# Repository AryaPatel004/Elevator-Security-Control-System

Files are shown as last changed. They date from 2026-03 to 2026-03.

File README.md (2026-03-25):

# Elevator Security Control System

A hardware design project for a secure elevator access system using multi-level authentication — **RFID, fingerprint, and capacitive keypad** — controlled by an **STM32G070CBT6 microcontroller**. The deliverable is a complete schematic and double-layer PCB design created in EasyEDA.

---

## 🔒 Overview

The system restricts elevator access to authenticated users only. Authentication follows a layered flow: RFID card scan → optional fingerprint or keypad verification → floor selection via touch keypad. Visual feedback is provided through a 7-segment display and 16 LEDs controlled via a shift register to minimize GPIO usage. A DC-DC converter handles the 24V to 5V step-down for the entire system.

---

## ✨ Key Features

- Multi-level authentication: RFID + fingerprint + capacitive keypad
- 16-channel touch keypad (TTP229) for floor selection
- 7-segment display for current/selected floor indication
- 74HC595 shift register to drive 16 LEDs with only 3 MCU pins
- W25Q128 serial flash for storing user credentials and access logs
- MC34063A DC-DC converter stepping 24V → 5V
- Double-layer PCB with modular section layout for clean signal routing

---

## 🔧 Components

| Component | Part Number | Purpose |
|---|---|---|
| Microcontroller | STM32G070CBT6 | Core processing and peripheral control |
| RFID Reader | RC522 | 13.56 MHz card scanning (ISO 14443A) |
| Fingerprint Sensor | ZW101 | Optical fingerprint capture and matching |
| Touch Keypad | TTP229 | 16-key capacitive input for floor selection |
| Shift Register | 74HC595 | Expand GPIO — drive 16 LEDs with 3 pins |
| Serial Flash | W25Q128 | 16MB non-volatile storage for user data |
| 7-Segment Display | — | Floor number display |
| DC-DC Converter | MC34063A | Step down 24V → regulated 5V |

### STM32G070CBT6 — Key Specs
- ARM Cortex-M0+, up to 64 MHz
- 128 KB Flash, 36 KB SRAM
- 2× I²C, 2× SPI, 4× USART
- 12-bit ADC, PWM timers
- 2.0V to 3.6V supply voltage

### RC522 RFID — Key Specs
- Operating frequency: 13.56 MHz
- Tag memory: 1 KB
- Interface: SPI
- Compatible with ISO 14443A tags (read & write)

### ZW101 Fingerprint Module — Key Specs
- Interface: UART
- Built-in optical sensor and matching processor
- Stores fingerprint templates internally

### W25Q128 Flash — Key Specs
- Capacity: 128 Mbit (16 MB)
- Interface: SPI (up to 104 MHz)
- 100,000 erase cycles per sector, >20 years data retention

---

## 🔐 Authentication Flow

```
User Approaches Elevator
        │
        ▼
  RFID Card Scan (RC522)
        │
        ├─ Not Recognized → Access Denied
        │
        └─ Recognized
                │
                ▼
   Fingerprint / Keypad Verification (ZW101 / TTP229)
                │
                ├─ Failed → Access Denied
                │
                └─ Verified
                        │
                        ▼
            Floor Selection via Touch Keypad
                        │
                        ▼
             Relay Triggered → Elevator Moves
```

---

## 🗂️ Repository Structure

```
elevator-security-control-system/
│
├── hardware/
│   ├── schematic.pdf              # Full schematic (EasyEDA export)
│   ├── pcb_design.pdf             # PCB layout (EasyEDA export)
│   └── gerber/                    # Gerber files ready for manufacturing
│       └── *.gbr
│
├── docs/
│   ├── pcb_front_back.png         # 2D front and back PCB render
│   └── bom.csv                    # Bill of Materials
│
├── .gitignore
└── README.md
```

---

## 🖥️ PCB Design Notes

Designed in **EasyEDA** as a double-layer board following this process:

1. **Schematic Creation** — All components and sub-circuits mapped out in four sections: Shift Register Circuit, Touch Button Circuit, Microcontroller Circuit, Voltage Converter Circuit, and Serial Flash Memory
2. **Footprint Assignment** — SMD packages selected to minimize board area
3. **Routing** — Short direct traces, decoupling capacitors placed close to IC power pins to reduce voltage ripple
4. **Component Grouping** — Each functional block assigned its own PCB region to simplify debugging and testing
5. **DRC & ERC Check** — Design verified for electrical and layout errors
6. **Gerber Export** — Files finalized and ready for manufacturing

---

## 🛠️ Built With

- [EasyEDA](https://easyeda.com/) — Schematic and PCB design
- [STM32G070CBT6 Datasheet](https://www.st.com/en/microcontrollers-microprocessors/stm32g070cb.html)
- [MFRC522 Datasheet](https://www.nxp.com/docs/en/data-sheet/MFRC522.pdf)
- [W25Q128 Datasheet](https://www.winbond.com/resource-files/w25q128jv%20spi%20revc%2011162016.pdf)

---

## 🔮 Future Scope

- Firmware development for STM32 to implement the full authentication logic
- Cloud connectivity for remote access control and audit logging
- Real-time elevator status reporting via wireless interface

---

## 👤 Author

**Arya Sureshbhai Patel**

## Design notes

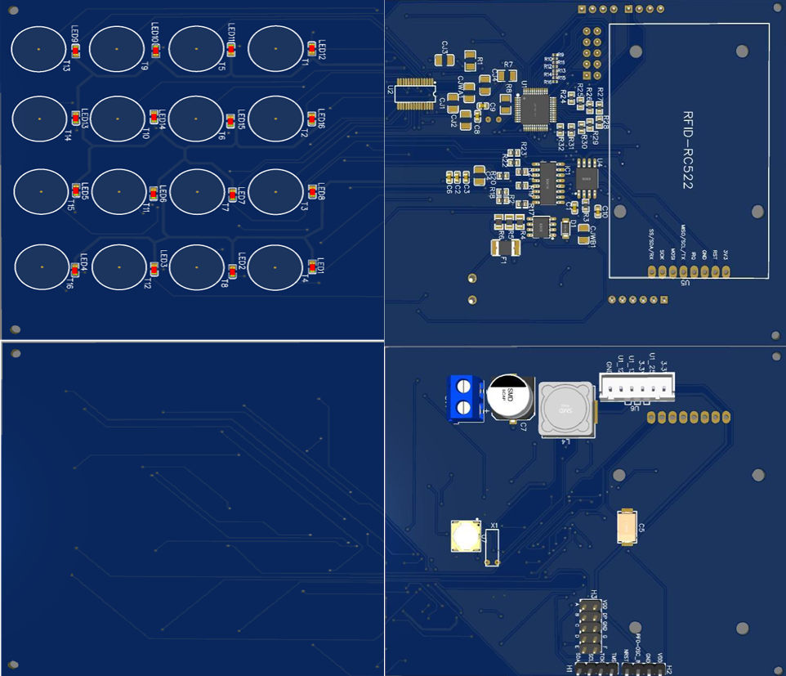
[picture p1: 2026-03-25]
docs/pcb_front_back.png

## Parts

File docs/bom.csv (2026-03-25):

ID | Name | Designator | Footprint | Quantity | Manufacturer Part | Manufacturer | Supplier | Supplier Part | Price | Pins | 3DModel | Contributor | JLCPCB Part Class | LCSC Assembly | SMT Type | Value | image | link
1 | 100uF | C7 | CAP-SMD_BD10.0-L10.3-W10.3-RD | 1 | VZH101M1HTR-1010 | LELON | LCSC | C134808 | 0.208 | 2 | CAP-SMD_L10.3-W10.3-H7.7-LS11.0 | LCSC |  | Yes | Extend |  |  | https://item.szlcsc.com/245683.html
2 | Header-Male-2.54_1x4 | H1,H2 | HDR-TH_4P-P2.54-V-M | 2 | B-2100S04P-A110 | Ckmtw(灿科盟) | LCSC | C124378 | 0.05 | 4 | HDR-TH_4P-P2.54-M-LI-1X4P | LCSC | Extended Part |  |  |  |  | https://item.szlcsc.com/502959.html
3 | Header-Male-2.54_2x5 | H3 | HDR-TH_10P-P2.54-V-M-R2-C5-S2.54 | 1 | 2*5p排针 2.54mm | null | LCSC | C28207 |  | 10 | HDR-TH_10P-P2.54-V-M-R2-C5-S2.54 | lcsc | Extended Part |  |  |  |  | https://item.szlcsc.com/502978.html
4 | 470uF | C5 | CAP-SMD_L7.3-W4.3-R-RD | 1 | CA45-D6R3K477T | Xiangyee | LCSC | C123270 | 0.866 | 2 | CASE-E_L7.3-W4.3-H4.1 | LCSC |  | Yes | Extend |  |  | https://item.szlcsc.com/91116.html
5 | 220uH | L4 | IND-SMD_L12.5-W12.5 | 1 | SWRB1205S-221MT | Sunlord | LCSC | C169391 |  | 2 | SMD-PIND_L12.5-W12.5-H8.0 | LCSC |  | Yes | Extend |  |  | https://item.szlcsc.com/421430.html
6 | WJ128V-5.0-2P | ST1 | CONN-TH_2P-P5.00 | 1 | WJ128V-5.0-2P | KANGNEX(康奈克斯电气) | LCSC | C8269 | 0.144 | 2 | CONN-TH_2P-P5.00 | LCEDA_Lib | Extended Part |  |  |  |  | https://www.szlcsc.com/?ref=editor
7 | HDR-1X6 | U6 | CONN-TH_6P-P2.50_HX25035-6A | 1 | HDR-1X6 | null | LCSC | C9900004873 |  | 6 | CONN-TH_6P-P2.50_HX25035-6A | LCSC |  |  |  |  |  | https://item.szlcsc.com/442613.html
8 | GT-TC155C-H0060-L50 | U7 | SW-SMD_4P-G-SWITCH-GT-TC155C-H0060-L50 | 1 | GT-TC155C-H0060-L50 | G-Switch(品赞) | LCSC | C5155558 | 0.15 | 4 | SW-SMD_4P-G-SWITCH-GT-TC155C-H0060-L50 | lcsc | Extended Part |  |  |  |  | https://atta.szlcsc.com/upload/public/pdf/source/20220909/B643400E9680C6559F0793AC5053044F.pdf
9 | Xtal 32.768KHz | X1 | XTAL 32.768KHZ | 1 |  |  |  |  |  | 2 |  | Maximvs |  |  |  | 32.768KHz
10 | 100nF | C1,C2,C8 | C0805 | 3 |  |  |  |  |  | 2 | C0603_L1.6-W0.8-H0.8 | LCEDA_Lib |  |  |  |  |  | https://item.szlcsc.com/362304.html
11 | 4.7uF | C3 | C0805 | 1 |  |  |  |  |  | 2 | C0603_L1.6-W0.8-H0.8 | LCEDA_Lib |  |  |  |  |  | https://item.szlcsc.com/362304.html
12 | 10pF | C9,C10 | C0805 | 2 |  |  |  |  |  | 2 | C0603_L1.6-W0.8-H0.8 | LCEDA_Lib |  |  |  |  |  | https://item.szlcsc.com/362304.html
13 | 104 | C4 | CAP_0805 | 1 | ? |  |  |  |  | 2 |  |  |  |  |  |  |  | https://item.szlcsc.com/279183.html
14 | 1u | CJ1,CJ2,CJ3,CJ4,CJWA1,CJWB1 | CAP_0805 | 6 | ? |  |  |  |  | 2 |  |  |  |  |  |  |  | https://item.szlcsc.com/279183.html
15 | 470pF | C6 | C0805 | 1 | 0603B471K500NT | FH | LCSC | C1620 | 0.003 | 2 | C0603_L1.6-W0.8-H0.8 | 立创EDA官方封装库 |  | Yes | Basic |  |  | https://item.szlcsc.com/362304.html
16 | B5819W | D1 | SOD-123_L2.8-W1.8-LS3.7-RD | 1 | B5819W | CJ | LCSC | C8598 | 0.024 | 2 | SOD-123_L2.8-W1.8-H1.4-LS3.7 | 官方封装库 |  | Yes | Basic |  | //image.lceda.cn/szlcsc/C8598.jpg | https://item.szlcsc.com/301422.html
17 | SMD1812P110TF/33 | F1 | F1812 | 1 | SMD1812P110TF/33 | RUILON | LCSC | C21000 | 0.144 | 2 | F1812_L4.5-W3.2-H1.0 | layout |  | Yes | Extend |  | //image.lceda.cn/szlcsc/C21000.jpg | https://item.szlcsc.com/343302.html
18 | SN74HC595DR | IC1 | SOIC-16_L9.9-W3.9-P1.27-LS6.0-BL | 1 | SN74HC595DR | TI | LCSC | C10092 | 0.325 | 16 | SOIC-16_L9.9-W3.9-H1.8-LS6.0-P1.27 | 官方封装库 |  | Yes | Extend |  | //image.lceda.cn/szlcsc/C10092.jpg | https://item.szlcsc.com/241229.html
19 | LED-0603_R | LED1,LED2,LED3,LED4,LED5,LED6,LED7,LED8,LED9,LED10,LED11,LED12,LED13,LED14,LED15,LED16 | LED0603_RED | 16 | 19-217/R6C-AL1M2VY/3T | EVERLIGHT(台湾亿光) | LCSC | C72044 | 0.021 | 2 | LED0603_Red | LCEDA_01
20 | 820k | R1,R7,R8 | RES_0805 | 3 | ? |  |  |  |  | 2 |  |  |  |  |  |  |  | https://item.szlcsc.com/279183.html
21 | 11K | R2 | R0805 | 1 | 0603WAF1102T5E | UniOhm | LCSC | C25950 | 0.001 | 2 | R0603_L1.6-W0.8-H0.8 | 立创EDA官方封装库 |  | Yes | Basic |  |  | https://item.szlcsc.com/137208.html
22 | 18K | R3 | R0805 | 1 | 0603WAF1802T5E | UniOhm | LCSC | C25810 | 0.001 | 2 | R0603_L1.6-W0.8-H0.8 | 立创EDA官方封装库 |  | Yes | Basic |  |  | https://item.szlcsc.com/137208.html
23 | 220 | R17,R18,R19,R20,R21,R22,R23,R24,R25,R26,R27,R28,R29,R30,R31,R32 | R0805 | 16 | 0603WAF1102T5E | UniOhm | LCSC | C25950 | 0.001 | 2 | R0603_L1.6-W0.8-H0.8 | 立创EDA官方封装库 |  | Yes | Basic |  |  | https://item.szlcsc.com/137208.html
24 | 1 | R4,R5,R6 | R0805 | 3 | 0805W8F360LT5E | Uniroyal Elec | LCSC | C35793 |  | 2 | R0805_L2.0-W1.3-H0.6 | LCSC |  | Yes | Extend |  |  | https://item.szlcsc.com/142685.html
25 | 220 | R9,R10,R11,R12,R13,R14,R15,R16 | 0805 | 8 |  |  |  |  |  | 2 |  | easyEDA
26 | Finger Print | T1,T2,T3,T4,T5,T6,T7,T8,T9,T10,T11,T12,T13,T14,T15,T16 | TOUCHPAD | 16 |  |  |  |  |  | 1 |  | Spacehuepfer
27 | STM32G070CBT6 | U1 | LQFP-48_L7.0-W7.0-P0.50-LS9.0-BL | 1 | STM32G070CBT6 | ST(意法半导体) | LCSC | C529338 | 1.449 | 48 | LQFP-48_L7.0-W7.0-H1.4-LS9.0-P0.50 | LCSC | Extended Part |  |  |  |  | https://atta.szlcsc.com/upload/public/pdf/source/20190808/C411336_D1D2DF7683029D856BA010BA7A5BF7EA.pdf
28 | TTP229-LSF | U2 | SSOP-28_150MIL | 1 | TTP229-LSF | Tontek Design Tech | LCSC | C191601 |  | 28 |  | LCSC
29 | MC34063ADR | U3 | SOIC-8_L4.9-W3.9-P1.27-LS6.0-BL | 1 | MC34063ADR | TI | LCSC |  |  | 8 | SOIC-8_L4.9-W3.9-H1.7-LS6.0-P1.27 | 87804271zpf |  | Yes | Extend
30 | W25Q128JVSSIQ | U4 | SOIC-8_L5.3-W5.3-P1.27-LS8.0-BL | 1 | W25Q128JVSSIQ | null | LCSC | C9900009643 |  | 8 | SOIC-8_L5.3-W5.3-H1.9-LS7.9-P1.27 | LCSC | Extended Part |  |  |  |  | https://item.szlcsc.com/63461.html
31 | RC522 MODULE | U5 | RC522 | 1 |  |  |  |  |  | 8 |  | Alexander Sevbo

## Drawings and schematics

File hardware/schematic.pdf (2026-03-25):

## Shift Register Circuit

## Touch button Circuit

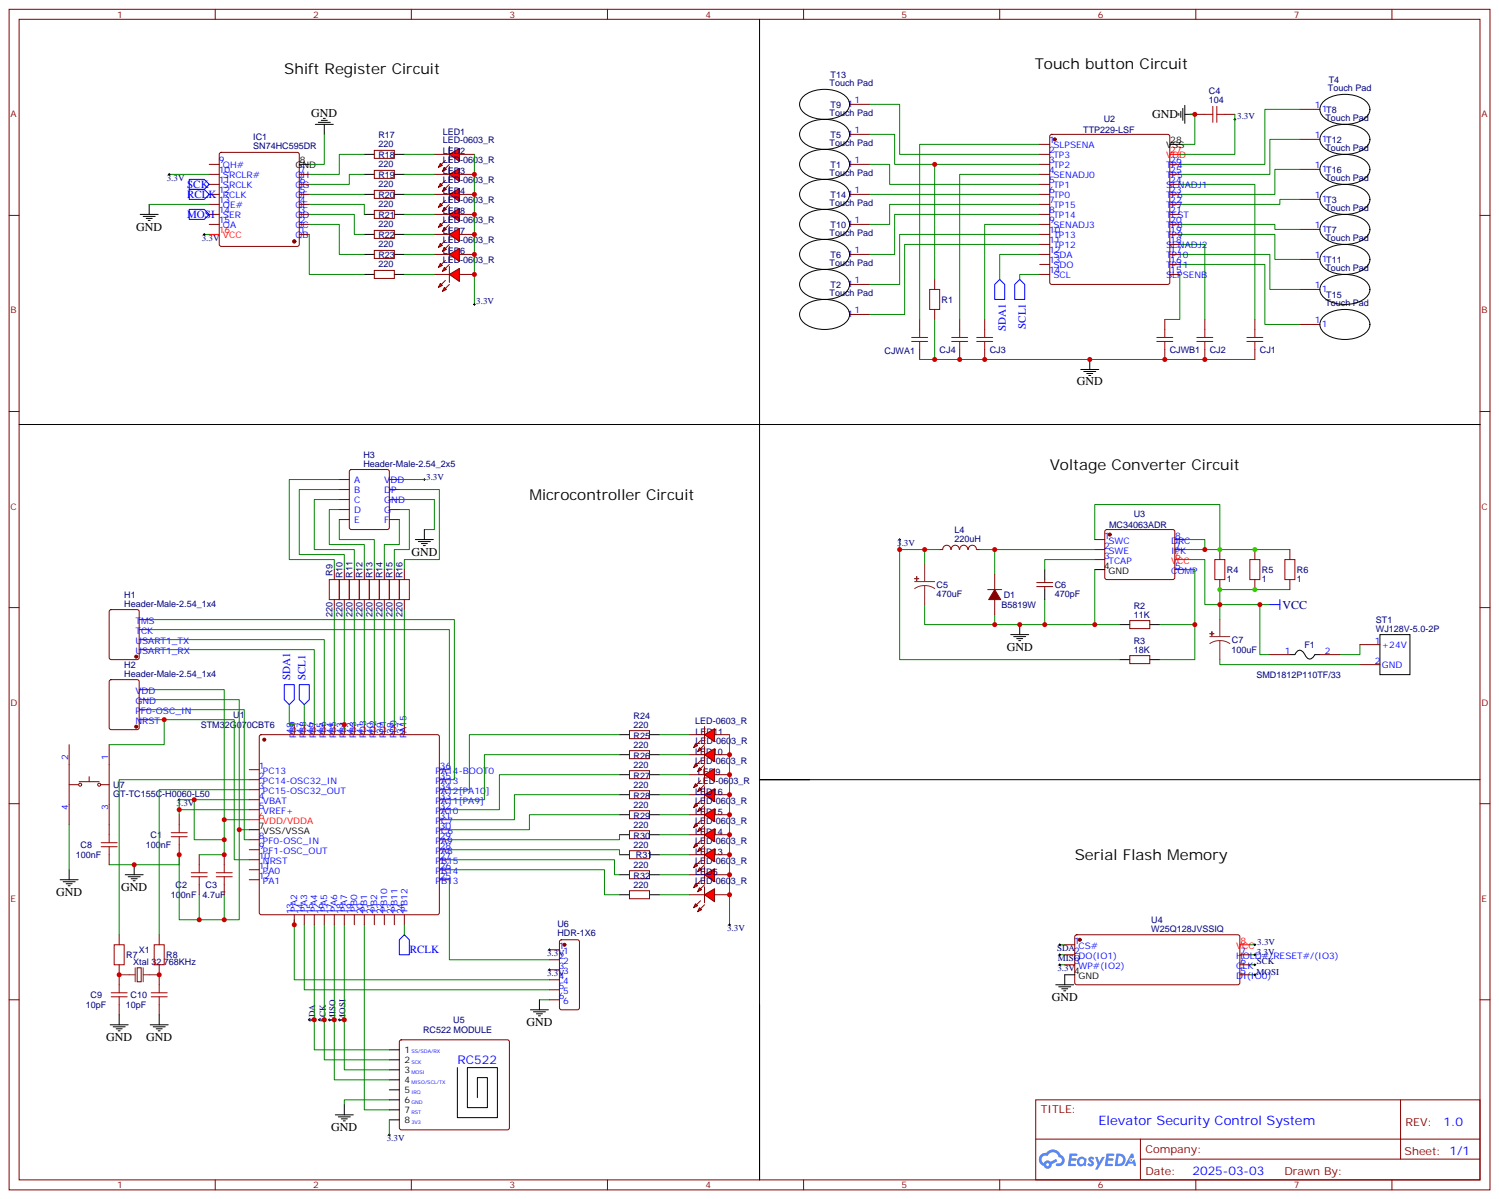
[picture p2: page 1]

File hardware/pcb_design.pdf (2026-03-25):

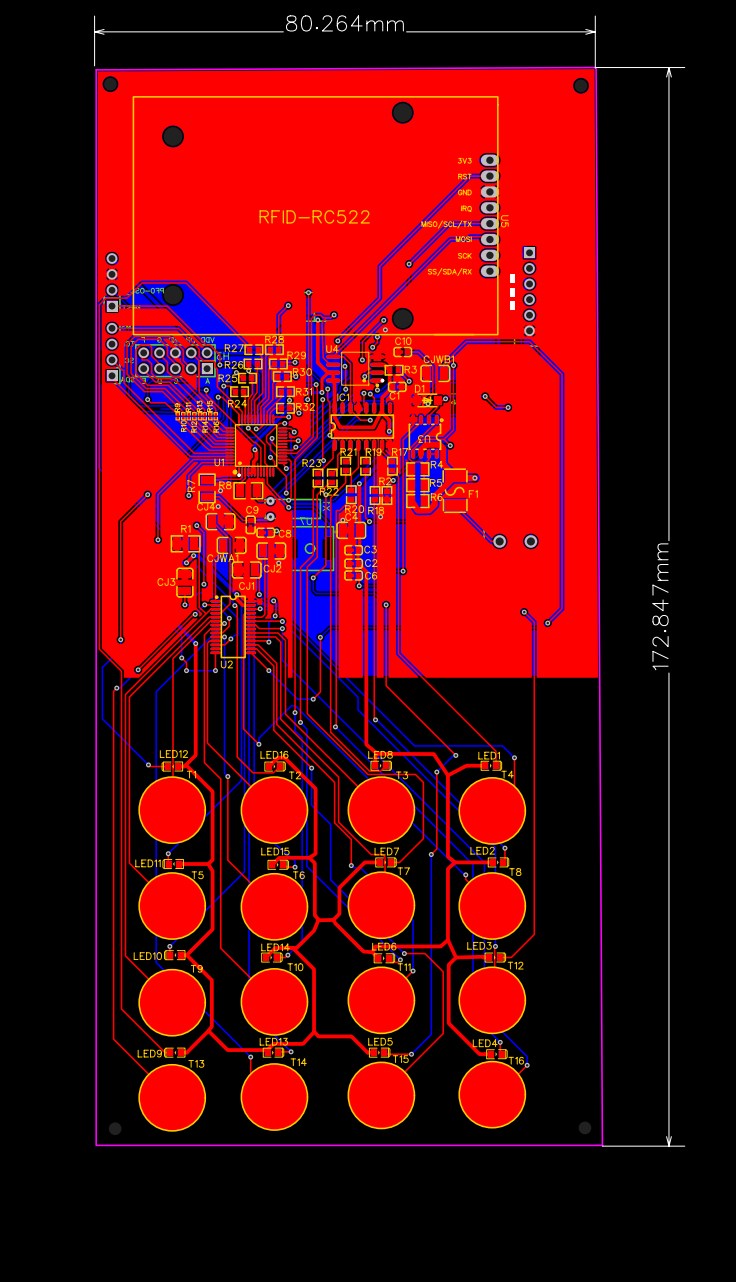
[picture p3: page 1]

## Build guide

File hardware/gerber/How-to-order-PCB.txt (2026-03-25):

How to Order PCB

Please refer to:
https://docs.easyeda.com/en/PCB/Order-PCB
